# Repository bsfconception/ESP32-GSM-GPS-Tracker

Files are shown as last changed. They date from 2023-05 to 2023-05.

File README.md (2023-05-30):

# ESP32-GSM-GPS-Tracker
IOT - ESP32 based GSM - GPS Tracker Kit




PinOut

## What is it?
This module is an autonomous GPS tracker based on an ESP32 processor.

It support regular SIM800 shield to manage 2G GSM communication and it is compatible with most 3.3V based GPS modules. With a dedicated software, the GPS localization of the module can be easily tracked using SMS exchanges or GPS localisation push on a dedicated web server.

The entire module (with Li-Ion battery) it small and light enough (70g) to be attached to an animal. The autonomy may vary based on the software and installed battery.

As an example, the module using SMS exchanges and UDP upload (each 3 minutes) runs during 14 hours with a 1000mAh battery.

Note : ONLY the PCB with NO components is provided, the mounter version will be proposed later

## Why did you make it?
This module is a spin-off of a horse tracker system than is used to monitor and alert during equestrian riding. This light version can be attached to any animal in order to follow him or retrieve him during rambles

## What makes it special?
The main features are: 
- ESP32 Wrover CPU 
- Li-Ion battery charger 
- USB connector 
- I2C connector 
- Serial programming connector 
- Buzzer 
- SIM800 PGM module pinOut 
- TOPGNSS GPS module pinout 
- Small form factor 
- Compatible with most 3.3V GPS Modules

It works with there modules SIM800 : https://fr.aliexpress.com/item/32370694678.html
original


GPS : 
https://fr.aliexpress.com/item/1005001634086877.html 
https://fr.aliexpress.com/item/32812641442.html 
https://fr.aliexpress.com/item/32949232692.html
HTB1meiUilsmBKNjSZFsq6yXSVXaX




Test Code
A test code will be provided soon on Github. It will be based on standard AT communication protocols

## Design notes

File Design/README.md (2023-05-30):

PETT_BSF

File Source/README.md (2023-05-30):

The test code is provided "as is" but 100% functionnal and compiled using Arduino IDE



The test code includes
- IO management (Buzzer, Button, Leds)
- GPS module management 
  - serial connection
  - NEMA decoding 
  - GPS position extraction (thanks to TinyGPS++ library)
  - Date and time retrieval 
- SIM800 GMS module control
  -  Serial connection
  -  AT protocol communication
  -  Module startup and configuration
  -  SMS Management

By default, the sotfware listen to SMS messages and triggers the corresping action
  - 'POS' : returns the GPS position of the module (including GooGleMap URL)
  - 'BEEP' : triggers 3 'beep' each 10 seconds. Repeated 30 times
  - 'UNBEEP': Cancels the 'BEEP' order

In order to adapt the test code to your SIM cart, only update these 2 lines :

  - strcpy( g_GSM_Config.Service , "+33xxxxxxxx"); //TODO : update SIM's message service
  - g_GSM_Config.PIN[0] = 0; //TODO : update SIM's PIN code











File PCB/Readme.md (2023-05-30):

Component placement

PETT_BSF-F Fab

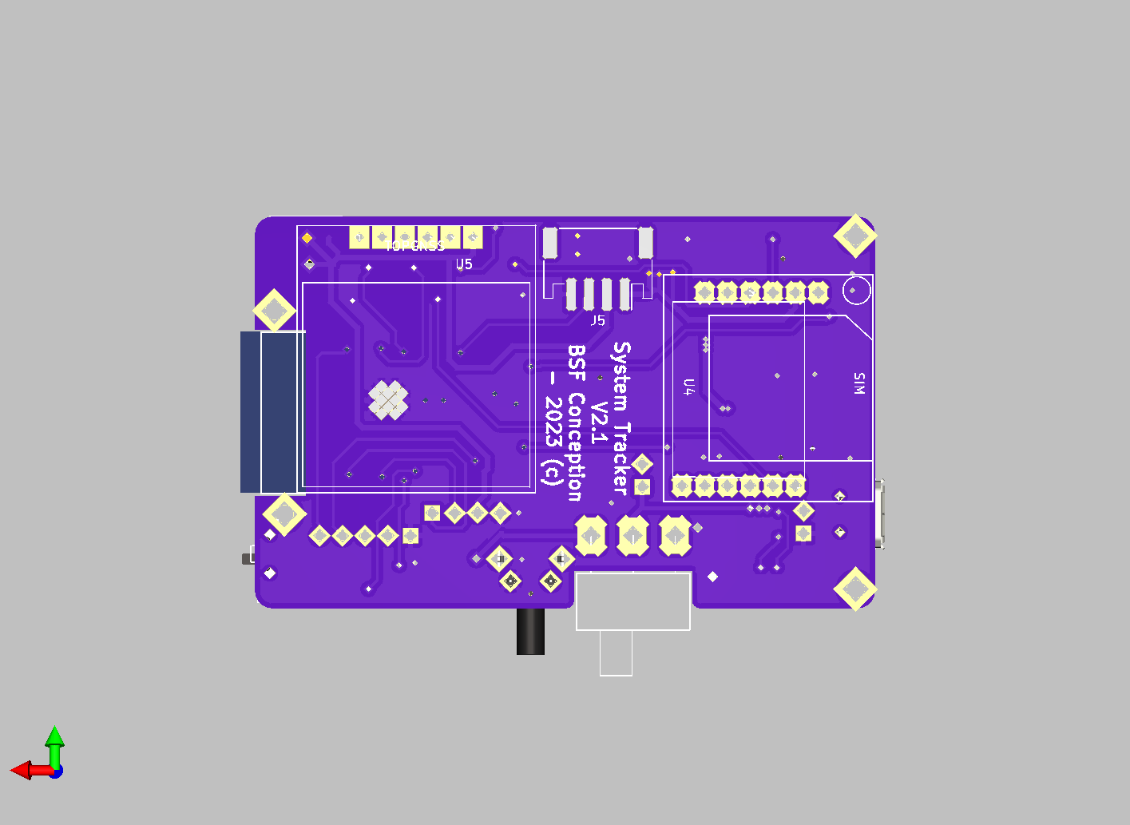
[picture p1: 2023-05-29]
Design/PCB_PinOutBack.png

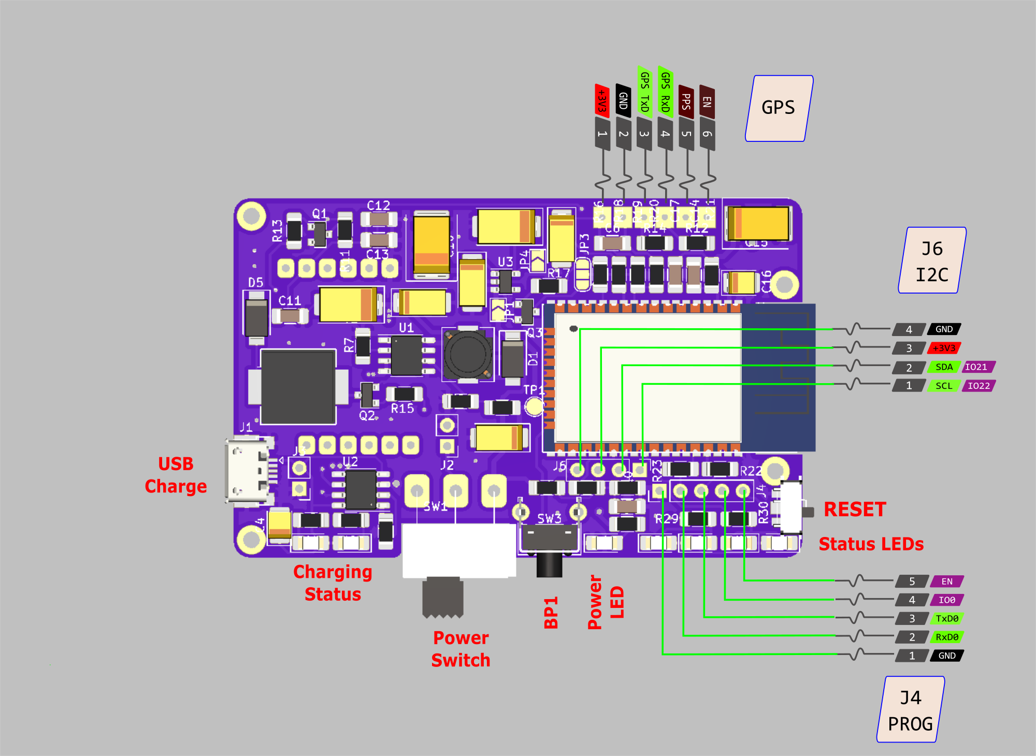
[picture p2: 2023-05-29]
Design/PinOut.png

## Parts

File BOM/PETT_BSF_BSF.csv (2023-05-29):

Source: | D:\ELECT_REPO\CAO_ELEC\Divers\PETT_BSF\SIM800\PETT_BSF.sch
Date: | 29/05/2023 15:55:18
Tool: | Eeschema (5.0.2)-1
Generator: | C:\Program Files\KiCad\bin\scripting\plugins/bom_csv_grouped_by_value.py
Component Count: | 74
Individual Components:
Item | Qty | Reference(s) | Value | LibPart | Footprint | Datasheet
 |  | BZ1 | Buzzer | Device:Buzzer | Livrary:Buzzer_CUI_CPT-9019S-SMT | ~
 |  | C1 | 470u | Device:C_Polarized | Capacitor_Tantalum_SMD:CP_EIA-7343-31_Kemet-D | ~
 |  | C2 | 220u | Device:C_Polarized | Capacitor_Tantalum_SMD:CP_EIA-6032-28_Kemet-C | ~
 |  | C3 | 220u | Device:C_Polarized | Capacitor_Tantalum_SMD:CP_EIA-6032-28_Kemet-C | ~
 |  | C4 | 47u | Device:C | Capacitor_Tantalum_SMD:CP_EIA-3528-21_Kemet-B | ~
 |  | C5 | 100n | Device:C | Capacitor_SMD:C_1206_3216Metric_Pad1.33x1.80mm_HandSolder | ~
 |  | C6 | 100n | Device:C | Capacitor_SMD:C_1206_3216Metric_Pad1.33x1.80mm_HandSolder | ~
 |  | C7 | 220u | Device:C_Polarized | Capacitor_Tantalum_SMD:CP_EIA-6032-28_Kemet-C | ~
 |  | C8 | 470uF | Device:C_Polarized | Capacitor_Tantalum_SMD:CP_EIA-7343-31_Kemet-D | ~
 |  | C9 | 220u | Device:C_Polarized | Capacitor_Tantalum_SMD:CP_EIA-6032-28_Kemet-C | ~
 |  | C10 | 1000u | Device:C_Polarized | Capacitor_Tantalum_SMD:CP_EIA-7360-38_Kemet-E | ~
 |  | C11 | 10p | Device:C | Capacitor_SMD:C_1206_3216Metric_Pad1.33x1.80mm_HandSolder | ~
 |  | C12 | 33p | Device:C | Capacitor_SMD:C_1206_3216Metric_Pad1.33x1.80mm_HandSolder | ~
 |  | C13 | 10u | Device:C | Capacitor_SMD:C_1206_3216Metric_Pad1.33x1.80mm_HandSolder | ~
 |  | C14 | 1u | Device:C_Polarized | Capacitor_SMD:C_1206_3216Metric_Pad1.33x1.80mm_HandSolder | ~
 |  | C15 | 1000u | Device:C_Polarized | Capacitor_Tantalum_SMD:CP_EIA-7360-38_Kemet-E | ~
 |  | C16 | 22u | Device:C_Polarized | Capacitor_Tantalum_SMD:CP_EIA-3528-21_Kemet-B | ~
 |  | C17 | 100n | Device:C | Capacitor_SMD:C_1206_3216Metric_Pad1.33x1.80mm_HandSolder | ~
 |  | D1 | SR540 | Device:D_Shockley | Diode_SMD:D_SMA | ~
 |  | D2 | STBY | Device:LED | LED_SMD:LED_1206_3216Metric_Pad1.42x1.75mm_HandSolder | ~
 |  | D3 | CHRG | Device:LED | LED_SMD:LED_1206_3216Metric_Pad1.42x1.75mm_HandSolder | ~
 |  | D4 | PWR | Device:LED | LED_SMD:LED_1206_3216Metric_Pad1.42x1.75mm_HandSolder | ~
 |  | D5 | DIODE | pspice:DIODE | Diode_SMD:D_SMA | ~
 |  | D6 | GREEN | Device:LED | LED_SMD:LED_1206_3216Metric_Pad1.42x1.75mm_HandSolder | ~
 |  | D7 | BLUE | Device:LED | LED_SMD:LED_1206_3216Metric_Pad1.42x1.75mm_HandSolder | ~
 |  | D8 | RED | Device:LED | LED_SMD:LED_1206_3216Metric_Pad1.42x1.75mm_HandSolder | ~
 |  | D9 | YELLOW | Device:LED | LED_SMD:LED_1206_3216Metric_Pad1.42x1.75mm_HandSolder | ~
 |  | J1 | USB_B_Micro | Connector:USB_B_Micro | Livrary:USB_Micro-B | ~
 |  | J2 | BAT | Connector_Generic:Conn_01x02 | Connector_PinHeader_2.54mm:PinHeader_1x02_P2.54mm_Vertical | ~
 |  | J3 | VIN | Connector_Generic:Conn_01x02 | Connector_PinHeader_2.54mm:PinHeader_1x02_P2.54mm_Vertical | ~
 |  | J4 | FDTI232+ | Connector_Generic:Conn_01x05 | Connector_PinHeader_2.54mm:PinHeader_1x05_P2.54mm_Vertical | ~
 |  | J5 | SENSOR | Connector_Generic:Conn_01x04 | Connector_JST:JST_PH_S4B-PH-SM4-TB_1x04-1MP_P2.00mm_Horizontal | ~
 |  | J6 | I2C | Connector_Generic:Conn_01x04 | Connector_PinHeader_2.54mm:PinHeader_1x04_P2.54mm_Vertical | ~
 |  | JP1 | 4V | Jumper:SolderJumper_2_Open | Jumper:SolderJumper-2_P1.3mm_Open_TrianglePad1.0x1.5mm | ~
 |  | JP3 | Jumper_3_Open | Jumper:Jumper_3_Open | Jumper:SolderJumper-3_P1.3mm_Open_RoundedPad1.0x1.5mm | ~
 |  | JP4 | 3V3 | Jumper:SolderJumper_2_Open | Jumper:SolderJumper-2_P1.3mm_Open_TrianglePad1.0x1.5mm | ~
 |  | L1 | 3u3 | Device:L_Ferrite | Inductor_SMD:L_6.3x6.3_H3 | ~
 |  | Q1 | MMBT3904 | Transistor_BJT:MMBT3904 | Package_TO_SOT_SMD:SOT-23 | https://www.onsemi.com/pub/Collateral/2N3903-D.PDF
 |  | Q2 | MMBT3904 | Transistor_BJT:MMBT3904 | Package_TO_SOT_SMD:SOT-23 | https://www.onsemi.com/pub/Collateral/2N3903-D.PDF
 |  | Q3 | MMBT3904 | Transistor_BJT:MMBT3904 | Package_TO_SOT_SMD:SOT-23 | https://www.onsemi.com/pub/Collateral/2N3903-D.PDF
 |  | R1 | 43K | Device:R | Resistor_SMD:R_1206_3216Metric_Pad1.30x1.75mm_HandSolder | ~
 |  | R2 | 4K7 | Device:R | Resistor_SMD:R_1206_3216Metric_Pad1.30x1.75mm_HandSolder | ~
 |  | R3 | 7K5 | Device:R | Resistor_SMD:R_1206_3216Metric_Pad1.30x1.75mm_HandSolder | ~
 |  | R4 | 47K | Device:R | Resistor_SMD:R_1206_3216Metric_Pad1.30x1.75mm_HandSolder | ~
 |  | R5 | 1K | Device:R | Resistor_SMD:R_1206_3216Metric_Pad1.30x1.75mm_HandSolder | ~
 |  | R6 | 1K | Device:R | Resistor_SMD:R_1206_3216Metric_Pad1.30x1.75mm_HandSolder | ~
 |  | R7 | 47K | Device:R | Resistor_SMD:R_1206_3216Metric_Pad1.30x1.75mm_HandSolder | ~
 |  | R8 | 47K | Device:R | Resistor_SMD:R_1206_3216Metric_Pad1.30x1.75mm_HandSolder | ~
 |  | R9 | 1K2 | Device:R | Resistor_SMD:R_1206_3216Metric_Pad1.30x1.75mm_HandSolder | ~
 |  | R10 | 7K5 | Device:R | Resistor_SMD:R_1206_3216Metric_Pad1.30x1.75mm_HandSolder | ~
 |  | R11 | 100K | Device:R | Resistor_SMD:R_1206_3216Metric_Pad1.30x1.75mm_HandSolder | ~
 |  | R12 | 470 | Device:R | Resistor_SMD:R_1206_3216Metric_Pad1.30x1.75mm_HandSolder | ~
 |  | R13 | 4K7 | Device:R | Resistor_SMD:R_1206_3216Metric_Pad1.30x1.75mm_HandSolder | ~
 |  | R14 | 470 | Device:R | Resistor_SMD:R_1206_3216Metric_Pad1.30x1.75mm_HandSolder | ~
 |  | R15 | 10K | Device:R | Resistor_SMD:R_1206_3216Metric_Pad1.30x1.75mm_HandSolder | ~
 |  | R16 | 1K | Device:R | Resistor_SMD:R_1206_3216Metric_Pad1.30x1.75mm_HandSolder | ~
 |  | R17 | 4K7 | Device:R | Resistor_SMD:R_1206_3216Metric_Pad1.30x1.75mm_HandSolder | ~
 |  | R18 | 1K | Device:R | Resistor_SMD:R_1206_3216Metric_Pad1.30x1.75mm_HandSolder | ~
 |  | R19 | 1K | Device:R | Resistor_SMD:R_1206_3216Metric_Pad1.30x1.75mm_HandSolder | ~
 |  | R20 | 5K1 | Device:R | Resistor_SMD:R_1206_3216Metric_Pad1.30x1.75mm_HandSolder | ~
 |  | R21 | 1K | Device:R | Resistor_SMD:R_1206_3216Metric_Pad1.30x1.75mm_HandSolder | ~
 |  | R22 | 470 | Device:R | Resistor_SMD:R_1206_3216Metric_Pad1.30x1.75mm_HandSolder | ~
 |  | R23 | 470 | Device:R | Resistor_SMD:R_1206_3216Metric_Pad1.30x1.75mm_HandSolder | ~
 |  | R29 | 4K7 | Device:R | Resistor_SMD:R_1206_3216Metric_Pad1.30x1.75mm_HandSolder | ~
 |  | R30 | 4K7 | Device:R | Resistor_SMD:R_1206_3216Metric_Pad1.30x1.75mm_HandSolder | ~
 |  | SW1 | POWER | Switch:SW_SPDT | Livrary:SW_Slide_1P2T_CK_OS102011MS2Q | ~
 |  | SW2 | RESET | Switch:SW_Push | Livrary:SW_PUSH_TS_1224W | ~
 |  | SW3 | BP1 | Switch:SW_Push | Button_Switch_THT:SW_Tactile_SPST_Angled_PTS645Vx83-2LFS | ~
 |  | U1 | FP6298 | custom:FP6298 | Package_SO:SOIC-8-1EP_3.9x4.9mm_P1.27mm_EP2.29x3mm
 |  | U2 | TP4056 | custom:TP4056 | Livrary:SOP-8_EP
 |  | U3 | ME6211-LDLN030 | custom:ME6211-LDLN030 | Package_TO_SOT_SMD:SOT-23-5
 |  | U4 | SIM800L | custom:SIM800L | Livrary:SIM800L
 |  | U5 | TOPGNSS | custom:TOPGNSS | Livrary:TOPGNSS
 |  | U7 | ESP32-WROVER | custom:ESP32-WROVER | Livrary:ESP32-WROVER
Collated Components:
Item | Qty | Reference(s) | Value | LibPart | Footprint | Datasheet
1 | 1 | BZ1 | Buzzer | Device:Buzzer | Livrary:Buzzer_CUI_CPT-9019S-SMT | ~
2 | 1 | C1 | 470u | Device:C_Polarized | Capacitor_Tantalum_SMD:CP_EIA-7343-31_Kemet-D | ~
3 | 4 | C2, C3, C7, C9 | 220u | Device:C_Polarized | Capacitor_Tantalum_SMD:CP_EIA-6032-28_Kemet-C | ~
4 | 1 | C4 | 47u | Device:C | Capacitor_Tantalum_SMD:CP_EIA-3528-21_Kemet-B | ~
5 | 3 | C5, C6, C17 | 100n | Device:C | Capacitor_SMD:C_1206_3216Metric_Pad1.33x1.80mm_HandSolder | ~
6 | 1 | C8 | 470uF | Device:C_Polarized | Capacitor_Tantalum_SMD:CP_EIA-7343-31_Kemet-D | ~
7 | 2 | C10, C15 | 1000u | Device:C_Polarized | Capacitor_Tantalum_SMD:CP_EIA-7360-38_Kemet-E | ~
8 | 1 | C11 | 10p | Device:C | Capacitor_SMD:C_1206_3216Metric_Pad1.33x1.80mm_HandSolder | ~
9 | 1 | C12 | 33p | Device:C | Capacitor_SMD:C_1206_3216Metric_Pad1.33x1.80mm_HandSolder | ~
10 | 1 | C13 | 10u | Device:C | Capacitor_SMD:C_1206_3216Metric_Pad1.33x1.80mm_HandSolder | ~
11 | 1 | C14 | 1u | Device:C_Polarized | Capacitor_SMD:C_1206_3216Metric_Pad1.33x1.80mm_HandSolder | ~
12 | 1 | C16 | 22u | Device:C_Polarized | Capacitor_Tantalum_SMD:CP_EIA-3528-21_Kemet-B | ~
13 | 1 | D1 | SR540 | Device:D_Shockley | Diode_SMD:D_SMA | ~
14 | 1 | D2 | STBY | Device:LED | LED_SMD:LED_1206_3216Metric_Pad1.42x1.75mm_HandSolder | ~
15 | 1 | D3 | CHRG | Device:LED | LED_SMD:LED_1206_3216Metric_Pad1.42x1.75mm_HandSolder | ~
16 | 1 | D4 | PWR | Device:LED | LED_SMD:LED_1206_3216Metric_Pad1.42x1.75mm_HandSolder | ~
17 | 1 | D5 | DIODE | pspice:DIODE | Diode_SMD:D_SMA | ~
18 | 1 | D6 | GREEN | Device:LED | LED_SMD:LED_1206_3216Metric_Pad1.42x1.75mm_HandSolder | ~
19 | 1 | D7 | BLUE | Device:LED | LED_SMD:LED_1206_3216Metric_Pad1.42x1.75mm_HandSolder | ~
20 | 1 | D8 | RED | Device:LED | LED_SMD:LED_1206_3216Metric_Pad1.42x1.75mm_HandSolder | ~
21 | 1 | D9 | YELLOW | Device:LED | LED_SMD:LED_1206_3216Metric_Pad1.42x1.75mm_HandSolder | ~
22 | 1 | J1 | USB_B_Micro | Connector:USB_B_Micro | Livrary:USB_Micro-B | ~
23 | 1 | J2 | BAT | Connector_Generic:Conn_01x02 | Connector_PinHeader_2.54mm:PinHeader_1x02_P2.54mm_Vertical | ~
24 | 1 | J3 | VIN | Connector_Generic:Conn_01x02 | Connector_PinHeader_2.54mm:PinHeader_1x02_P2.54mm_Vertical | ~
25 | 1 | J4 | FDTI232+ | Connector_Generic:Conn_01x05 | Connector_PinHeader_2.54mm:PinHeader_1x05_P2.54mm_Vertical | ~
26 | 1 | J5 | SENSOR | Connector_Generic:Conn_01x04 | Connector_JST:JST_PH_S4B-PH-SM4-TB_1x04-1MP_P2.00mm_Horizontal | ~
27 | 1 | J6 | I2C | Connector_Generic:Conn_01x04 | Connector_PinHeader_2.54mm:PinHeader_1x04_P2.54mm_Vertical | ~
28 | 1 | JP1 | 4V | Jumper:SolderJumper_2_Open | Jumper:SolderJumper-2_P1.3mm_Open_TrianglePad1.0x1.5mm | ~
29 | 1 | JP3 | Jumper_3_Open | Jumper:Jumper_3_Open | Jumper:SolderJumper-3_P1.3mm_Open_RoundedPad1.0x1.5mm | ~
30 | 1 | JP4 | 3V3 | Jumper:SolderJumper_2_Open | Jumper:SolderJumper-2_P1.3mm_Open_TrianglePad1.0x1.5mm | ~
31 | 1 | L1 | 3u3 | Device:L_Ferrite | Inductor_SMD:L_6.3x6.3_H3 | ~
32 | 3 | Q1, Q2, Q3 | MMBT3904 | Transistor_BJT:MMBT3904 | Package_TO_SOT_SMD:SOT-23 | https://www.onsemi.com/pub/Collateral/2N3903-D.PDF
33 | 1 | R1 | 43K | Device:R | Resistor_SMD:R_1206_3216Metric_Pad1.30x1.75mm_HandSolder | ~
34 | 5 | R2, R13, R17, R29, R30 | 4K7 | Device:R | Resistor_SMD:R_1206_3216Metric_Pad1.30x1.75mm_HandSolder | ~
35 | 2 | R3, R10 | 7K5 | Device:R | Resistor_SMD:R_1206_3216Metric_Pad1.30x1.75mm_HandSolder | ~
36 | 3 | R4, R7, R8 | 47K | Device:R | Resistor_SMD:R_1206_3216Metric_Pad1.30x1.75mm_HandSolder | ~
37 | 6 | R5, R6, R16, R18, R19, R21 | 1K | Device:R | Resistor_SMD:R_1206_3216Metric_Pad1.30x1.75mm_HandSolder | ~
38 | 1 | R9 | 1K2 | Device:R | Resistor_SMD:R_1206_3216Metric_Pad1.30x1.75mm_HandSolder | ~
39 | 1 | R11 | 100K | Device:R | Resistor_SMD:R_1206_3216Metric_Pad1.30x1.75mm_HandSolder | ~
40 | 4 | R12, R14, R22, R23 | 470 | Device:R | Resistor_SMD:R_1206_3216Metric_Pad1.30x1.75mm_HandSolder | ~
41 | 1 | R15 | 10K | Device:R | Resistor_SMD:R_1206_3216Metric_Pad1.30x1.75mm_HandSolder | ~
42 | 1 | R20 | 5K1 | Device:R | Resistor_SMD:R_1206_3216Metric_Pad1.30x1.75mm_HandSolder | ~
43 | 1 | SW1 | POWER | Switch:SW_SPDT | Livrary:SW_Slide_1P2T_CK_OS102011MS2Q | ~
44 | 1 | SW2 | RESET | Switch:SW_Push | Livrary:SW_PUSH_TS_1224W | ~
45 | 1 | SW3 | BP1 | Switch:SW_Push | Button_Switch_THT:SW_Tactile_SPST_Angled_PTS645Vx83-2LFS | ~
46 | 1 | U1 | FP6298 | custom:FP6298 | Package_SO:SOIC-8-1EP_3.9x4.9mm_P1.27mm_EP2.29x3mm
47 | 1 | U2 | TP4056 | custom:TP4056 | Livrary:SOP-8_EP
48 | 1 | U3 | ME6211-LDLN030 | custom:ME6211-LDLN030 | Package_TO_SOT_SMD:SOT-23-5
49 | 1 | U4 | SIM800L | custom:SIM800L | Livrary:SIM800L
50 | 1 | U5 | TOPGNSS | custom:TOPGNSS | Livrary:TOPGNSS
51 | 1 | U7 | ESP32-WROVER | custom:ESP32-WROVER | Livrary:ESP32-WROVER

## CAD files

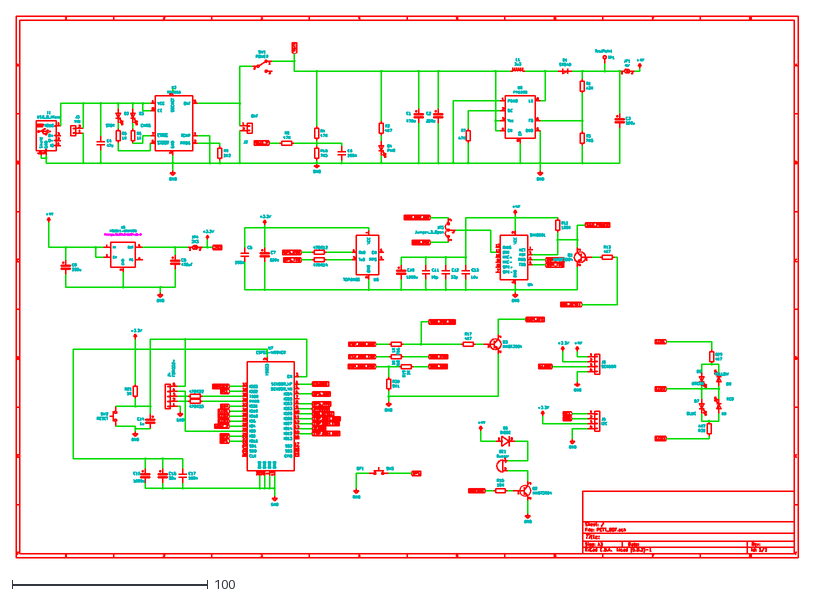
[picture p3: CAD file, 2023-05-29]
Design/PETT_BSF.dxf
400.0 x 277.0

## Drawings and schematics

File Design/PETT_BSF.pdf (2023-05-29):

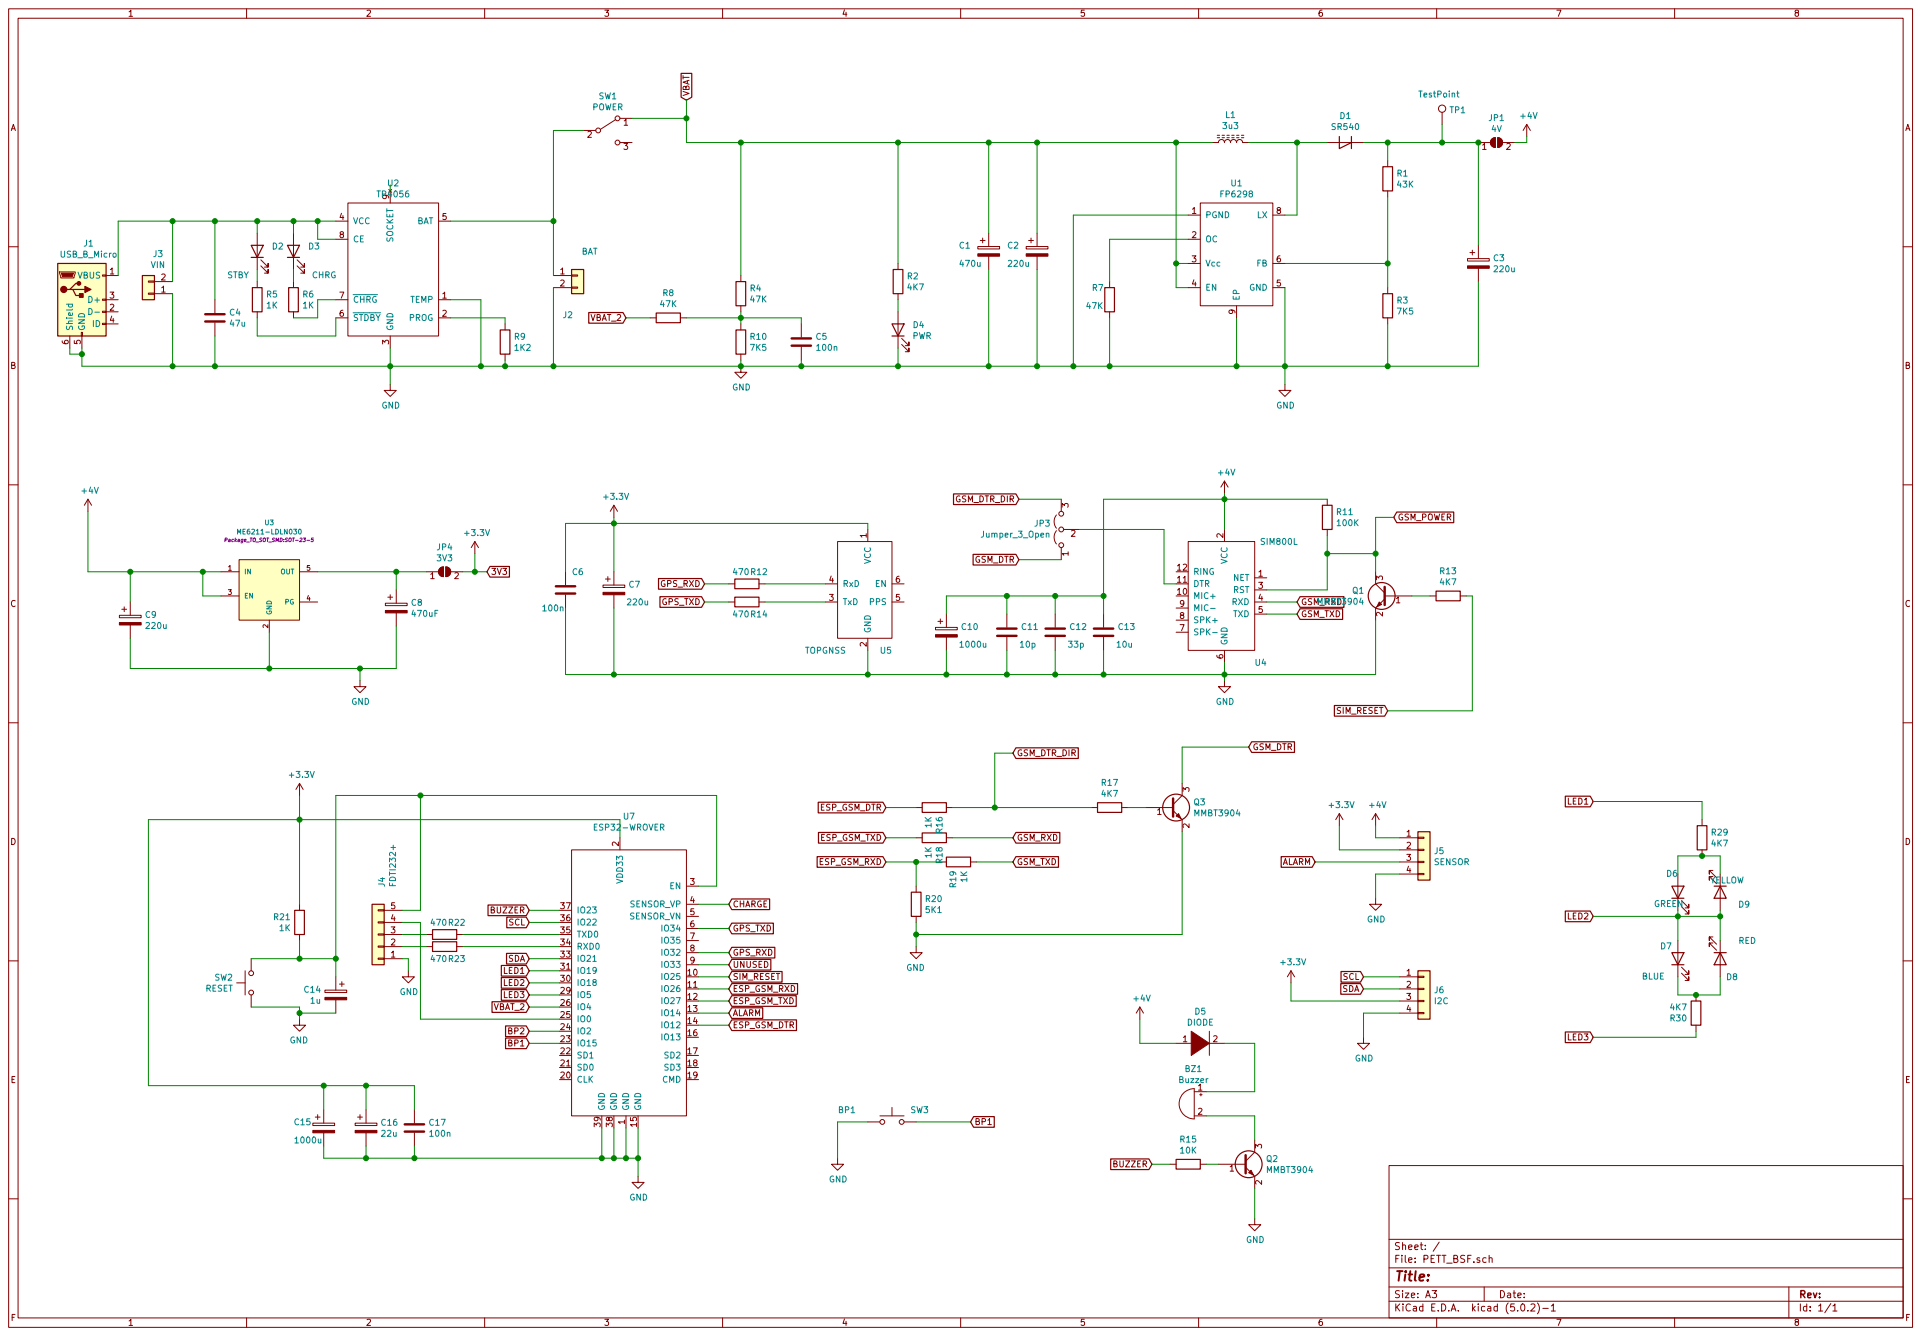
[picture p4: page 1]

3 VCC 4 BAT 5 STDBY 6 CHRG 7 CE 8 SOCKET

2 RST 3 RXD 4 TXD 5 GND

2 TxD 3 RxD 4 PPS 5 EN 6 TOPGNSS U5 C10

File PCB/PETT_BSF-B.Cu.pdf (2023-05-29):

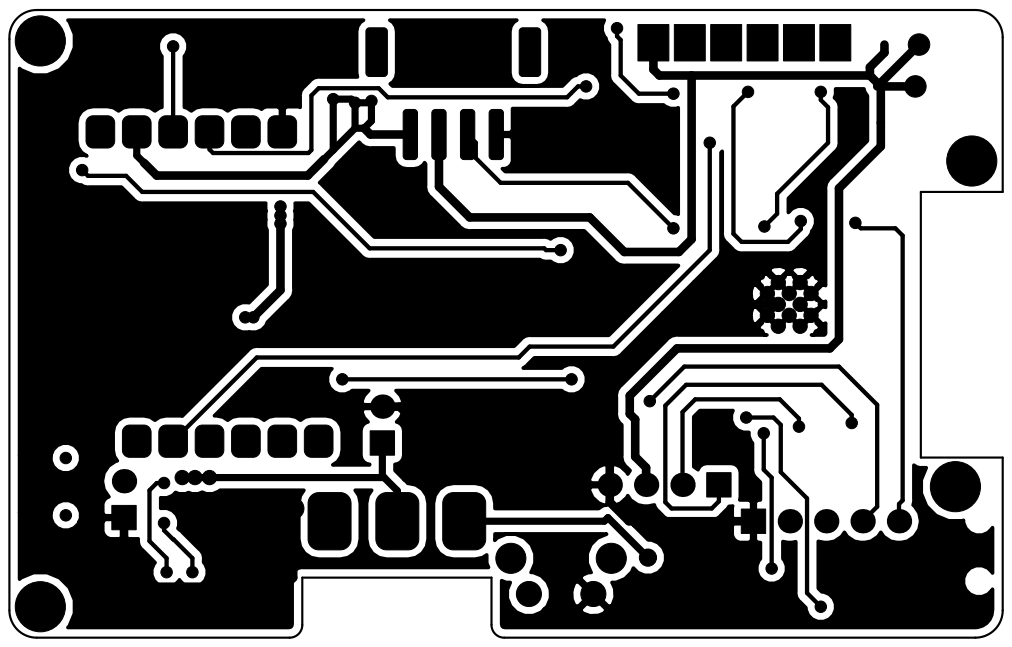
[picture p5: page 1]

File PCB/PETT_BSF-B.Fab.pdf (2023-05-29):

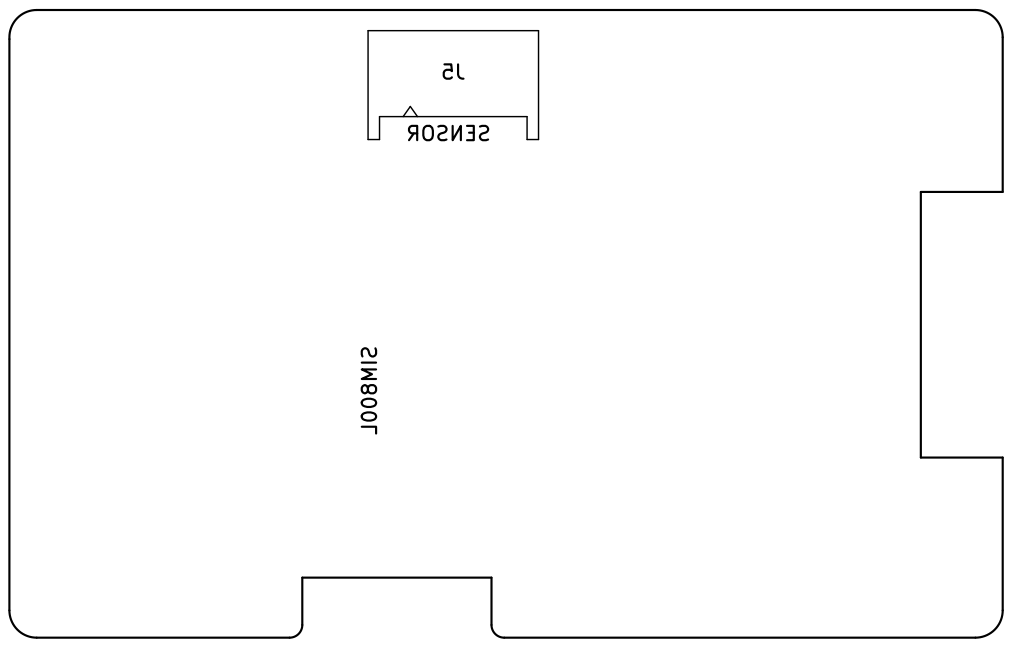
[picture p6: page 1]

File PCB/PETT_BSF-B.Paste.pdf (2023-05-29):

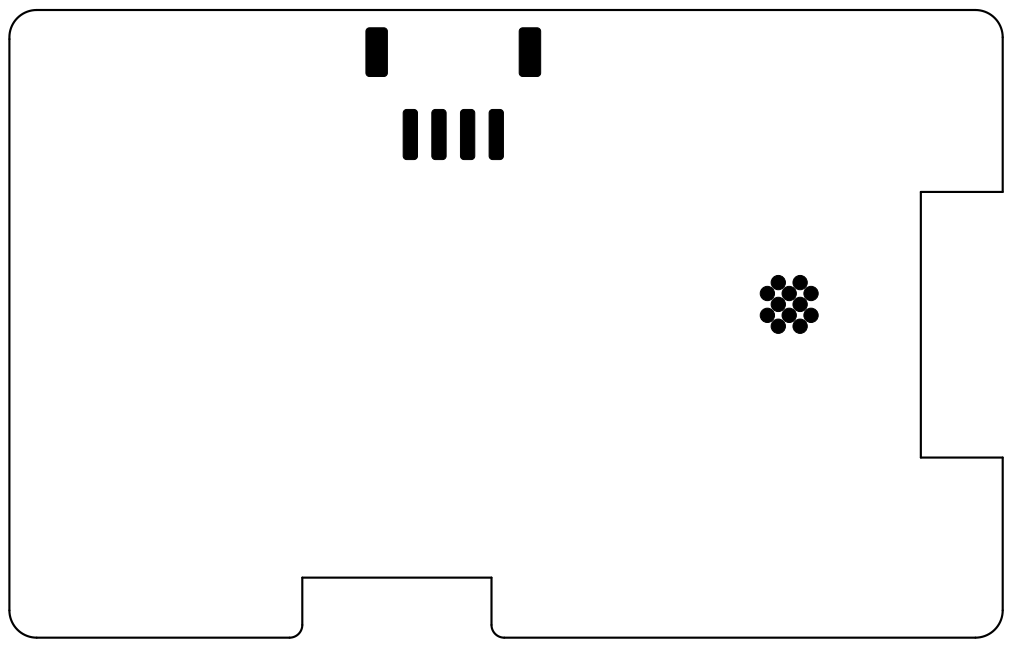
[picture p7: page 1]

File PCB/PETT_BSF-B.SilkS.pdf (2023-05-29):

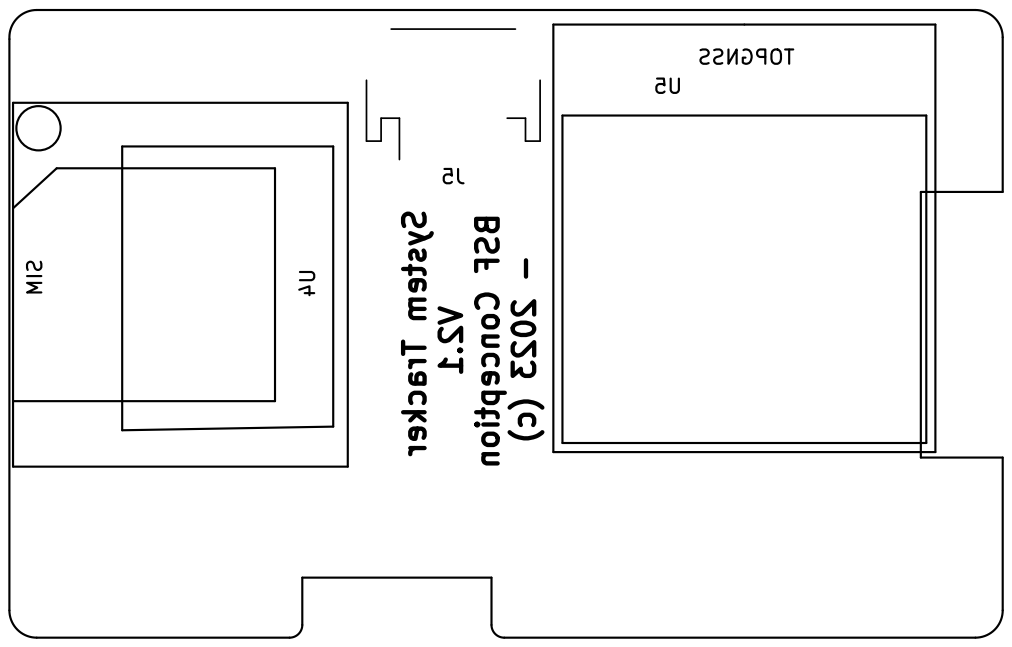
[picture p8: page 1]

System Tracker V2.1 BSF Conception - 2023 (c) U5 TOPGNSS U4 SIM

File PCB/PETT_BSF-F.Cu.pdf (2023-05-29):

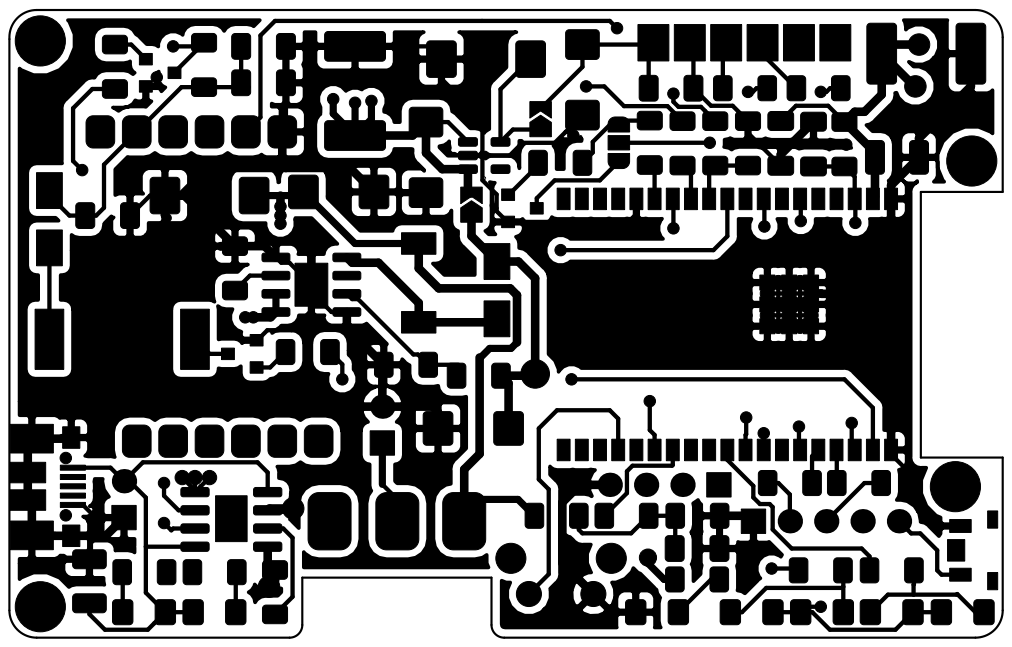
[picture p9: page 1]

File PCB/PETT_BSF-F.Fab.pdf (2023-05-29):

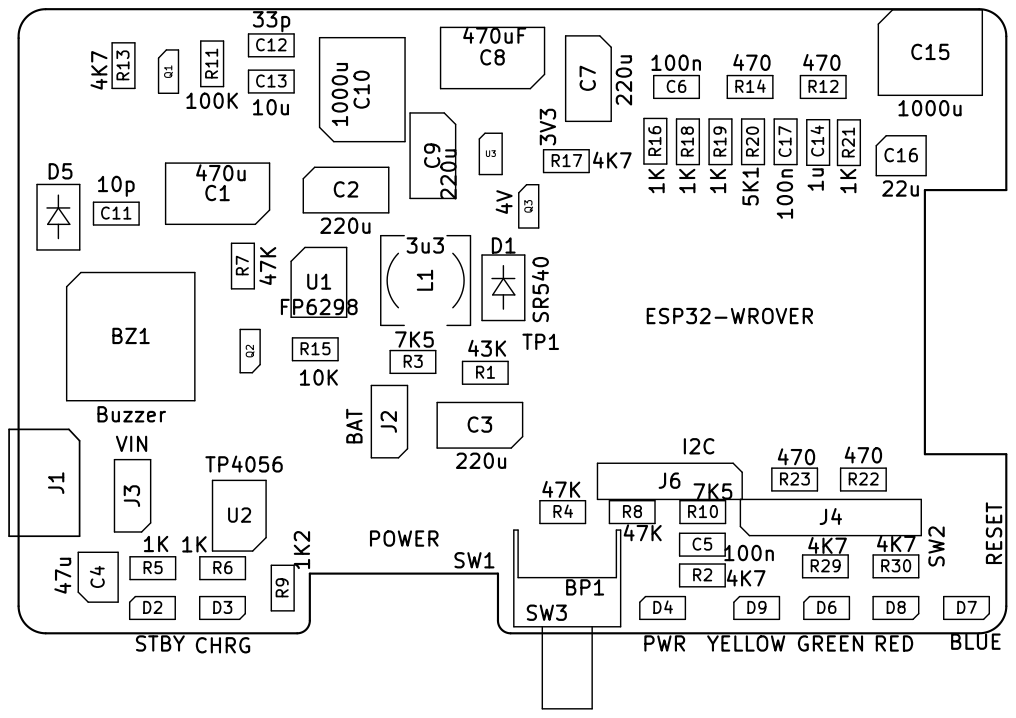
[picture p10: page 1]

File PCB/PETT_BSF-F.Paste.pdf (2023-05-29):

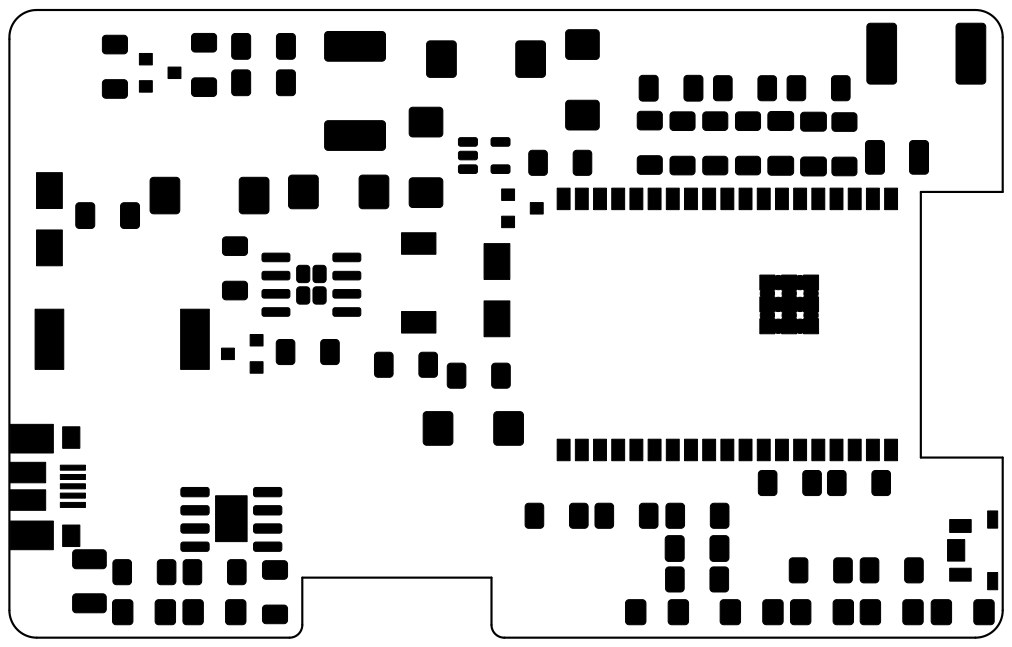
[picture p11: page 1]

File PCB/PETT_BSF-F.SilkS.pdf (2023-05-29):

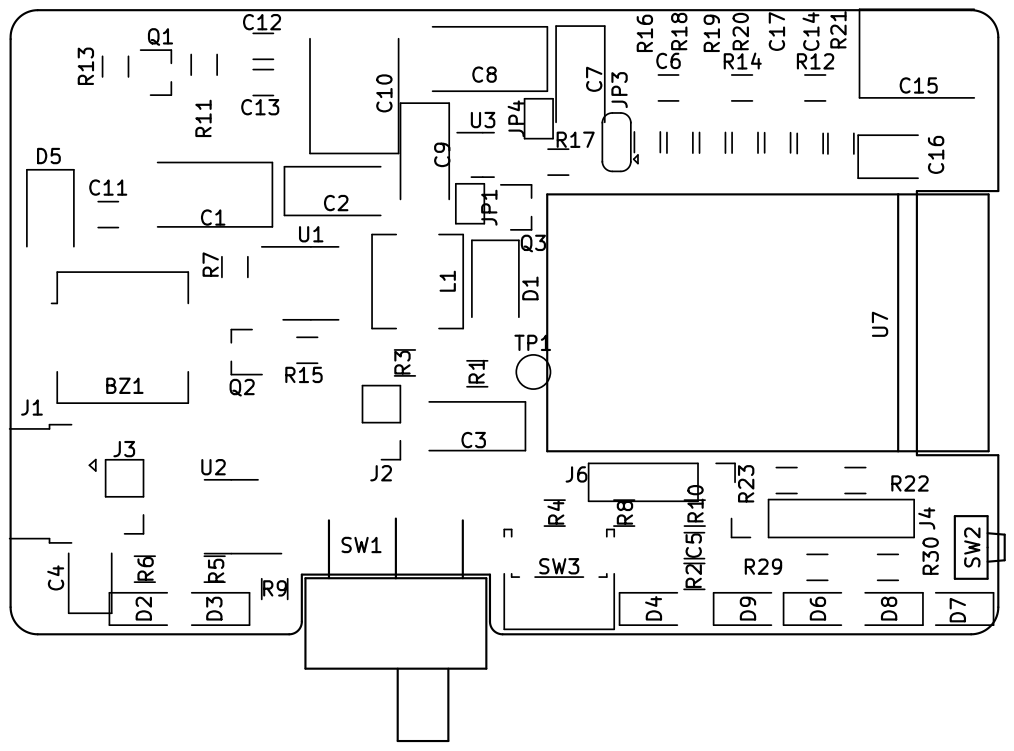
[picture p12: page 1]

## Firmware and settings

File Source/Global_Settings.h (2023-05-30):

/***************************************************************************************************************
MIT License

Copyright (c) 2023 BSF Conception

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
THE SOFTWARE IS PROVIDED "AS IS", WITHOUT WARRANTY OF ANY KIND, EXPRESS OR
IMPLIED, INCLUDING BUT NOT LIMITED TO THE WARRANTIES OF MERCHANTABILITY,
FITNESS FOR A PARTICULAR PURPOSE AND NONINFRINGEMENT. IN NO EVENT SHALL THE
AUTHORS OR COPYRIGHT HOLDERS BE LIABLE FOR ANY CLAIM, DAMAGES OR OTHER
LIABILITY, WHETHER IN AN ACTION OF CONTRACT, TORT OR OTHERWISE, ARISING FROM,
OUT OF OR IN CONNECTION WITH THE SOFTWARE OR THE USE OR OTHER DEALINGS IN THE
SOFTWARE.
***************************************************************************************************************/

#define BUZZER        23
#define CHARGING      36

#define LED_1            19
#define LED_2            18
#define LED_3            5

#define MODEM_TX             27
#define MODEM_RX             26
#define SIM800_RESET        25
#define SIM800_DTR            12

#define I2C_SDA              21
#define I2C_SCL              22

#define GPS_TX             32
#define GPS_RX             34

#define BP1           15  

#define VBATPIN       4

/*********************************************/

#define LED_NONE     -1
#define LED_YELLOW   0
#define LED_GREEN    1
#define LED_RED      2
#define LED_BLUE     3




#define ERROR_NOGMSNET  1
#define ERROR_CGATT1    2
#define ERROR_CIPSTART  3
#define ERROR_CIPSEND   4
#define ERROR_CIPSENDKO 5
#define ERROR_CIPSPRT   6
#define ERROR_CGATT0    7
#define ERROR_CONNECTKO  8
#define ERROR_PLANEMODE  9
#define ERROR_BADCONFIG  10
#define ERROR_CICCR    11
#define ERROR_DISABLED    12


#define MODULEID_SIZE       16
#define PHONENUMBER_SIZE  16

#include <Wire.h>

#define _min(a,b) ((a)<(b)?(a):(b))
#define _max(a,b) ((a)>(b)?(a):(b))


#define _minmax(a,b,c) ((a)<(b)?(b):( (a)>(c)?(c):(a)  ))
#define _minmaxloop(a,b,c) ((a)<(b)?(c):( (a)>(c)?(b):(a)  ))



#define BUTTON_NONE      0
#define BUTTON_UP        5
#define BUTTON_DOWN      6

#define PUSH_NONE      0
#define PUSH_SHORT      1
#define PUSH_LONG       2


#define uS_TO_S_FACTOR 1000000ULL  /* Conversion factor for micro seconds to seconds */



char _CRLF[] = "\r\n";

char _OK[] = "OK";
char _AT[]  = "AT";   // check COM
//char _ATF[] = "AT&F";  // Factory default config -> to remove
char _ATD[] = "AT&D0";  // ignores status on DTR (change on 12/05/2023))
char _ATEO[] = "ATE0";  // ECHO OFF
char _ATCLIP1[] = "AT+CLIP=1";    // Request calling line identification
char _ATCMEE0[] = "AT+CMEE=0";    // No Mobile Error Code
char _ATCMEE2[] = "AT+CMEE=2";    // Verbose  Mobile Error Code
char _ATCMGF1[] = "AT+CMGF=1";    // set the SMS mode to text 
char _ATCNMI2[] = "AT+CNMI=2,0";  // SMS message indication
char _ATCPMS[] = "AT+CPMS=\"SM\",\"SM\",\"SM\""; // manage SMS storage
char _ATCPBS[] = "AT+CPBS=\"SM\"";     // select phonebook memory storage


char _ATCMGL[] ="AT+CMGL=\"REC UNREAD\"";  // check is an SMS is present
char _ATCMGDA[] ="AT+CMGDA=\"DEL INBOX\"";   // delete this sms   *SIM800 AT+CMGD              
char _ATCMGDALL[] ="AT+CMGDA=\"DEL ALL\"";   // delete all sms    *SIM800 AT+CMGD
char _ATGSN[] = "AT+GSN";  // rtetrieve the IMEI of the device
char _ATPWRDWN[] = "AT+CPOWD=1";  // Power down


char _ATCGATT1[] PROGMEM ="AT+CGATT=1";     // Attached GPRS Service

char _ATCSCA[] PROGMEM ="AT+CSCA=\"";     // send SMS service address
char _ATCPIN[] PROGMEM ="AT+CPIN=";       //  enter PIN code
char _ATCSCS[] PROGMEM ="AT+CSCS=\"GSM\"";     // select character set
char _ATCGSMS3[] PROGMEM ="AT+CGSMS=3";      // service for SMS message
char _ATCREG[] PROGMEM ="AT+CREG?";       // manange Registration
char _ATCSQ[] PROGMEM ="AT+CSQ";   // read RSSI
char _ATCNUM[] PROGMEM ="AT+CNUM";   // read SIM Num



typedef struct {
  int Valid;
  int SatValid; // the nb of sal is valid
  int NbSat;
  int LocValid; // the location is valid
  double Lat;
  double Lng;
  int AltValid; // the altitude is valid
  double Altitude;
  int SpdValid; // the speed is valid
  double Speed;
  double Accuracy;
  long TimeStamp;
//  long GPSDelay;
  char DateTime[32];
  char Date[12];
  char Time[12];
//  int Compas;
} GPS_Coordinates;




typedef struct {
  int Button;
  int Charging;
  int VBat;
  int VBatValue;
  int RSSI;
} USER_INPUT;


 
typedef struct {
  // HT_Home
  char Service[PHONENUMBER_SIZE];
  char PIN[MODULEID_SIZE];  
} GSM_Config;

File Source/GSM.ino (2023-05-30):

/***************************************************************************************************************
MIT License

Copyright (c) 2023 BSF Conception

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
THE SOFTWARE IS PROVIDED "AS IS", WITHOUT WARRANTY OF ANY KIND, EXPRESS OR
IMPLIED, INCLUDING BUT NOT LIMITED TO THE WARRANTIES OF MERCHANTABILITY,
FITNESS FOR A PARTICULAR PURPOSE AND NONINFRINGEMENT. IN NO EVENT SHALL THE
AUTHORS OR COPYRIGHT HOLDERS BE LIABLE FOR ANY CLAIM, DAMAGES OR OTHER
LIABILITY, WHETHER IN AN ACTION OF CONTRACT, TORT OR OTHERWISE, ARISING FROM,
OUT OF OR IN CONNECTION WITH THE SOFTWARE OR THE USE OR OTHER DEALINGS IN THE
SOFTWARE.
***************************************************************************************************************/


extern unsigned long IRAM_ATTR _millis();

extern char Response_Data[256];
extern char TOOLS_Buffer[256];

void setup_GSM_Modem()
{
    // Set GSM module baud rate and UART pins
    g_SerialDebug.println("Setup GSM Baud Rate");
  g_SerialAT.begin(9600, SERIAL_8N1, MODEM_RX, MODEM_TX);

}


/**************************************************/
void BootGSMModule( void )
{
  g_SerialDebug.println("GSM_Reset");

  GSM_Reset();

  GSM_WaitForModuleReady();

  g_SerialDebug.println("GSM_Init");
  GSM_Init(1);
  
  g_UserInput.RSSI = GSM_ReadRSSI();
}
/**************************************************/

void GSM_Reset( void )
{
  digitalWrite(SIM800_RESET, HIGH);
  delay(1000);
  digitalWrite(SIM800_RESET, LOW);
  delay(1000);
}


void GSM_GetStatus( void )
{
    // checks if the module is started
  g_GMSStatus = GSM_sendATcommand(_AT, _OK, 2000);
}


void GSM_WaitForModuleReady( void )
{
int answer;
  do
  {
   UpdateStartupBlinker();
   answer = GSM_sendATcommand(_AT, _OK, 2000);
  }
  while(answer == 0);
}

/*****************************************************************************************/


char GSM_UpdateService()
{
char answer=0, i;
String Command;

  
 // send SMS service address
  Command = (char *)_ATCSCA;
  Command = Command  + g_GSM_Config.Service;
  Command = Command  + "\"";
  answer = GSM_sendATcommand((char *)Command.c_str(), _OK, 500);
  if(answer == 0)
    return(0);  
  delay(200);
  return(1);
} 

int GSM_Init( int display )
{
char answer=0, i;
String Command;
int TryLoop = 0;
  

  g_GMSStatus = 0;
  g_GMSNetwork = 0;

  while( g_SerialAT.available() > 0) 
    g_SerialAT.read();    // Clean the input buffer

  UpdateStartupBlinker();

  // checks if the module is started
  TryLoop = 0;
  do
  {
    answer = GSM_sendATcommand(_AT, _OK, 2000);
    delay(1000);
    TryLoop++;
  }
  while( (TryLoop<20) && (answer==0) );
  if(answer == 0)
    return(0);
  delay(50);
    
  UpdateStartupBlinker();

  TryLoop = 0;
  do
  {
    answer = GSM_sendATcommand(_ATD, _OK, 2000);
    TryLoop++;
  }
  while( (TryLoop<3) && (answer==0) );
  if(answer == 0)     return(0);  

  UpdateStartupBlinker();

  // switch off echo
  TryLoop = 0;
  do
  {
    answer = GSM_sendATcommand(_ATEO, _OK, 2000);
    TryLoop++;
  }
  while( (TryLoop<3) && (answer==0) );
  if(answer == 0)     return(0);  

  UpdateStartupBlinker();

  //enter PIN code
  if( strlen( g_GSM_Config.PIN ) > 0 )
  {
    Command = (char*)_ATCPIN;
    Command = Command  + g_GSM_Config.PIN;
    // send PIN number
    TryLoop = 0;
    do
    {
      answer = GSM_sendATcommand((char*)Command.c_str(), _OK, 2000);
      TryLoop++;
    }
    while( (TryLoop<3) && (answer==0) );
      
    if(answer == 0)     return(0);  
  }
  
  UpdateStartupBlinker();
  
  // Request calling line identification
  TryLoop = 0;
  do
  {
    answer = GSM_sendATcommand(_ATCLIP1, _OK, 2000);
    TryLoop++;
  }
  while( (TryLoop<3) && (answer==0) );
  if(answer == 0)     return(0);  

  UpdateStartupBlinker();

  TryLoop = 0;
  do
  {
  answer = GSM_sendATcommand(_ATCMEE0, _OK, 2000);
    TryLoop++;
  }
  while( (TryLoop<3) && (answer==0) );
  if(answer == 0)     return(0);
    
  UpdateStartupBlinker();
  
  TryLoop = 0;
  do
  {
    answer = GSM_sendATcommand((char *)_ATCSCS, _OK, 2000);
    TryLoop++;
  }
  while( (TryLoop<3) && (answer==0) );
 
  if(answer == 0)     return(0);  

  UpdateStartupBlinker();

  // init SMS storage
  // Disable messages about new SMS from the GSM module 
  TryLoop = 0;
  do
  {
    answer = GSM_sendATcommand(_ATCNMI2, _OK, 2000);
    TryLoop++;
  }
  while( (TryLoop<3) && (answer==0) );
  
  if(answer == 0)     return(0);  
  
  UpdateStartupBlinker();

// send AT command to init memory for SMS in the SIM card
  TryLoop = 0;
  do
  {
    answer = GSM_sendATcommand(_ATCPMS, /*"+CPMS:"*/ _OK, 2000);
    TryLoop++;
  }
  while( (TryLoop<3) && (answer==0) );
  
  if(answer == 0)     return(0);  

  UpdateStartupBlinker();

  
  // select phonebook memory storage
  TryLoop = 0;
  do
  {
    answer = GSM_sendATcommand(_ATCPBS, _OK, 2000);
    TryLoop++;
  }
  while( (TryLoop<3) && (answer==0) );
  
  if(answer == 0)     return(0);  

  UpdateStartupBlinker();

  TryLoop = 0;
  do
  {
    answer = GSM_sendATcommand((char *)_ATCGSMS3, _OK, 500);
    TryLoop++;
  }
  while( (TryLoop<3) && (answer==0) );
  
  if(answer == 0)     return(0);  

  UpdateStartupBlinker();
  
  // set the SMS mode to text 
  TryLoop = 0;
  do
  {
    answer = GSM_sendATcommand(_ATCMGF1, _OK, 2000);
    TryLoop++;
  }
  while( (TryLoop<3) && (answer==0) );
  
  if(answer == 0)     return(0);  
  
  UpdateStartupBlinker();

  if( strlen( g_GSM_Config.Service ) > 0 )
  {
    // send SMS service address
    Command = _ATCSCA;
    Command = Command  + g_GSM_Config.Service;
    Command = Command  + "\"";
    
    g_SerialDebug.println( (char *)Command.c_str() );

    TryLoop = 0;
    do
    {
      answer = GSM_sendATcommand((char *)Command.c_str(), _OK, 1000);
      TryLoop++;
      UpdateStartupBlinker();

    }
    while( (TryLoop<3) && (answer==0) );
  
    if(answer == 0)
      return(0);  
    delay(200);
  }  
    
  UpdateStartupBlinker();
 
  GSM_GetStatus();

  UpdateStartupBlinker();

  GSM_CheckNetworkRegistration();

  g_SerialDebug.print("g_GMSStatus : ");
  g_SerialDebug.println(g_GMSStatus);
  g_SerialDebug.print("g_GMSNetwork : ");
  g_SerialDebug.println(g_GMSNetwork);
  
  return(1);
}


void GSM_CheckNetworkRegistration( void )
{
char i;  
uint8_t x=0,  answer=0;

  g_GMSNetwork = 0;
  
  i = 0;
  do
  {
    answer = GSM_sendATcommand((char *)_ATCREG, _OK , 1000);
    if(answer == 0)     
      return;  
  
    if( strstr( Response_Data, "+CREG:0,1" ) != NULL )
    {
      g_GMSNetwork = 1;
      return;  
    }
    if( strstr( Response_Data, "+CREG:0,5" ) != NULL )
    {
      g_GMSNetwork = 1;
      return;  
    }
    delay(2000);
    i++;
  }  
  while(i<10);
}
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
